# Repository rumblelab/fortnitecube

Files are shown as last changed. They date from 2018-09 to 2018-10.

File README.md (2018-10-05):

# How to build your own Fortnite purple cube - Kevin

In this repo you will find: 
1. [Ardunio code](https://github.com/rumblelab/fortnitecube/tree/master/FortnitePurpleCube)
2. [.STL files for 3D printing the cube](https://github.com/rumblelab/fortnitecube/tree/master/3dKevin)
3. [BOM - Bill of Materials and links to each item](https://github.com/rumblelab/fortnitecube/blob/master/FortniteCube_BOM.pdf)
4. [Version 2: BOM - Bill of Materials and links to each item](https://github.com/rumblelab/fortnitecube/blob/master/V2_FortniteCube_BOM.pdf)
5. Wiring diagram 
6. .OGG sound file 

## Contributing to the code:
Please feel free to contribute! We appreciate any and all suggestions to help make the code for this project more efficient. Submit your ideas and we will review.

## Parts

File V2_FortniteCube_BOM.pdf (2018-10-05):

## VERSION TWO:

## Fortnite Purple Cube (Kevin) - Bill of Materials

## Created by Moultrie Ball

### RumbleLab (http://www.rumblelab.com)

If you’d like more detailed instructions, comment on our YouTube video here. (https://youtu.be/xSYryboQGLk)

Item | Price | Link | Notes
Piezo Element | $1.50 | SparkFun (https://www.sparkfun.com/products/10293)
Micro Servo | $5.95 | Adafruit (https://www.adafruit.com/product/169)
Audio Amplifier | $3.95 | Adafruit (https://www.adafruit.com/product/2130)
FX Mini Sound Board | $14.95 | Adafruit (https://www.adafruit.com/product/2342)
Trinket - Mini Microcontroller | $6.95 | Adafruit (https://www.adafruit.com/product/1501) | *Need 2 of these
Lithium Ion Battery | $7.95 | Adafruit (https://www.adafruit.com/product/1578)
(2) 40mm Round External Magnet Electronic Speakers | $7.37 | Amazon (https://www.amazon.com/gp/product/B00XXG5GX4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) | We’d love your help in supporting our channel. Affiliate link here: Amazon (https://amzn.to/2Rz2iX0)
On-Off Power Button | $1.95 | Adafruit (https://www.adafruit.com/product/1683)
Lilon/LiPoly Backpack Add-On for Pro Trinket | $4.95 | Adafruit (https://www.adafruit.com/product/2124)
NeoPixel Digital RGB LED Strip - White 60 LED - 1 meter | $24.95 | Adafruit (https://www.adafruit.com/product/1138?length=1)
Maker Paste | $6.95 | Adafruit (https://www.adafruit.com/product/3217) | Only get this if you don’t want to use a soldering iron
30 AWG Flexible Silicone Wire (Non-affiliate link) | $9.74 | Amazon (https://www.amazon.com/gp/product/B01KQ2JNLI/ref=oh_aui_detailpage_o02_s00?ie=UTF8&psc=1) | We’d love your help in supporting our channel. Affiliate link here: Amazon (https://amzn.to/2NrdWUm)
Hatchbox 3D Printer Filament - Glow in the Dark (Non-affiliate link) | $26.99 | Amazon (https://www.amazon.com/gp/product/B00M0CS73S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) | We’d love your help in supporting our channel. Affiliate link here: Amazon (https://amzn.to/2oLxHZ7)

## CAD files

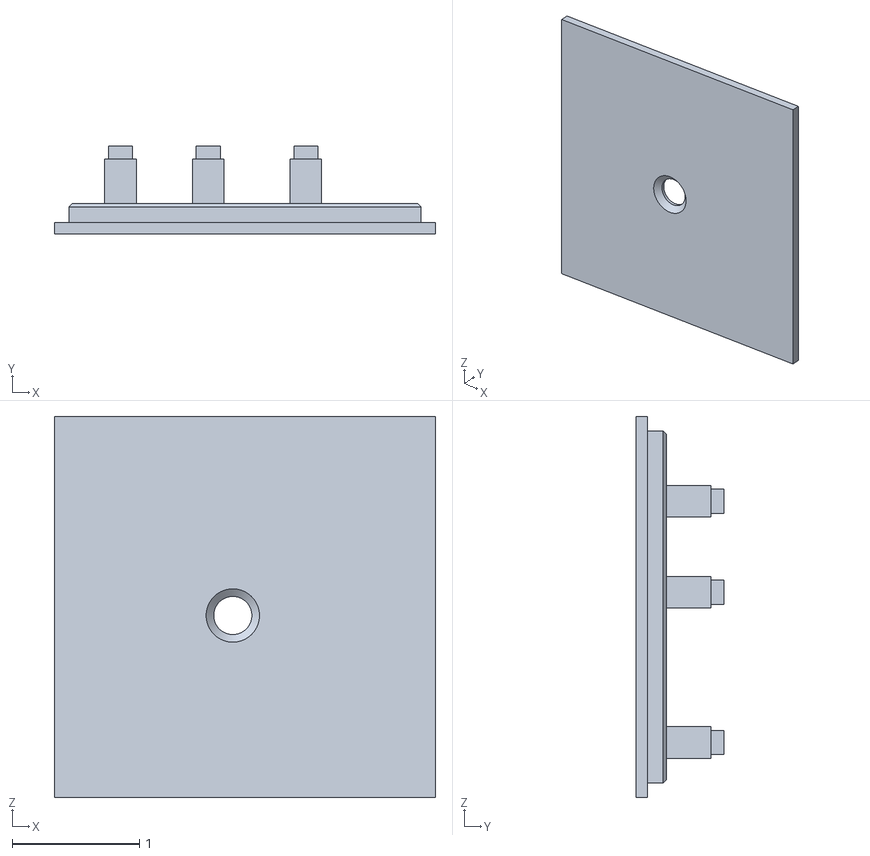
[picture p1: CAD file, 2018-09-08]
3dKevin/KevinBase.stl
3.00 x 0.69 x 3.00

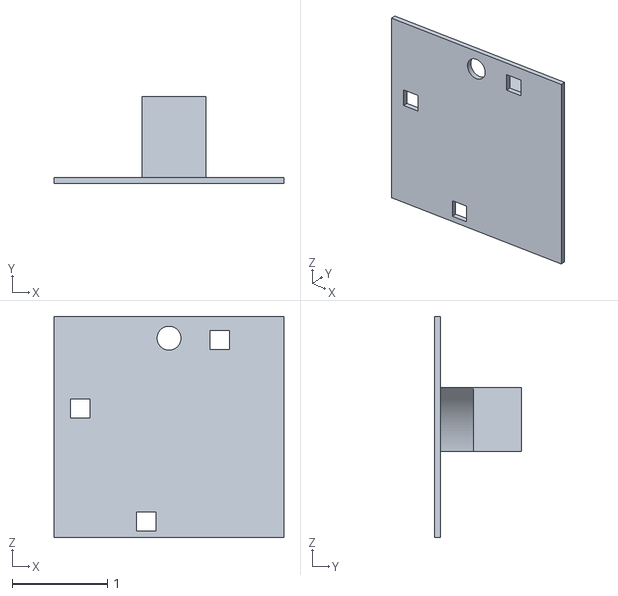
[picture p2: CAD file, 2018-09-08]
3dKevin/TopHat.stl
2.41 x 0.91 x 2.32

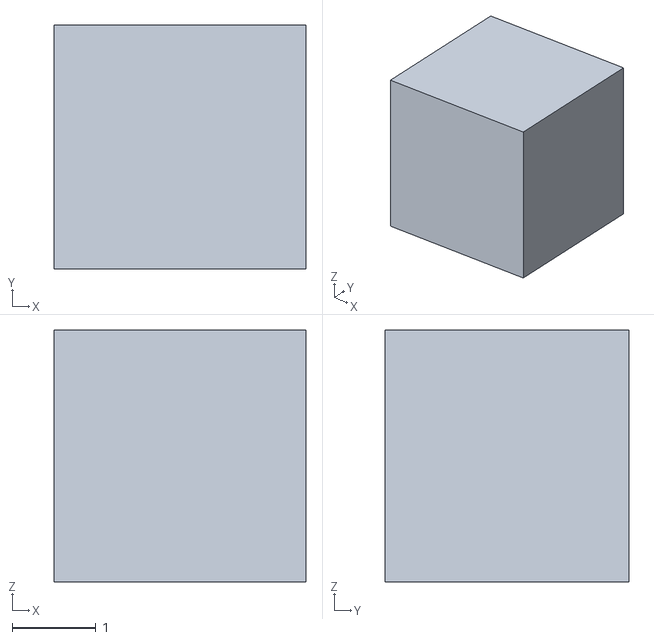
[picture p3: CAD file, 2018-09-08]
3dKevin/KevinBody.stl
3.00 x 2.90 x 3.00

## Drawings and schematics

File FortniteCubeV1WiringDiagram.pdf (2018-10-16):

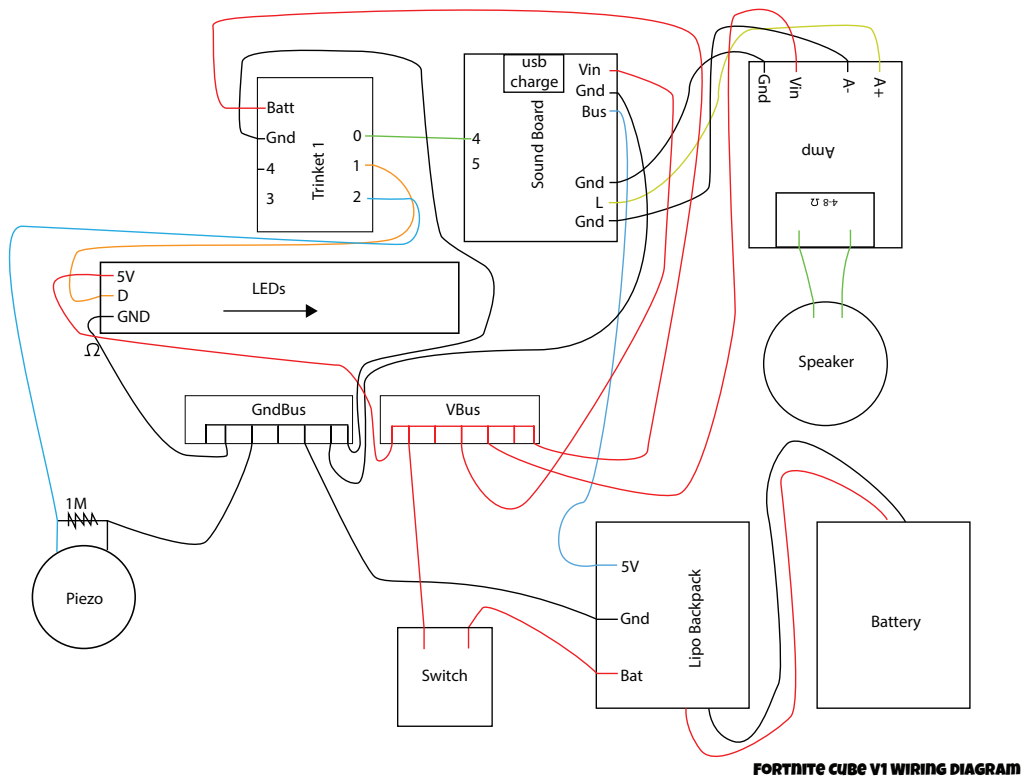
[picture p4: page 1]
Sound Board; Speaker; Battery; Lipo Backpack; Vin Gnd; Gnd; Bus; Trinket 1; Batt; Switch; Bat; Vin; GndBus; VBus; LEDs; GND; Piezo; usb charge

Fortnite Cube V1 Wiring Diagram

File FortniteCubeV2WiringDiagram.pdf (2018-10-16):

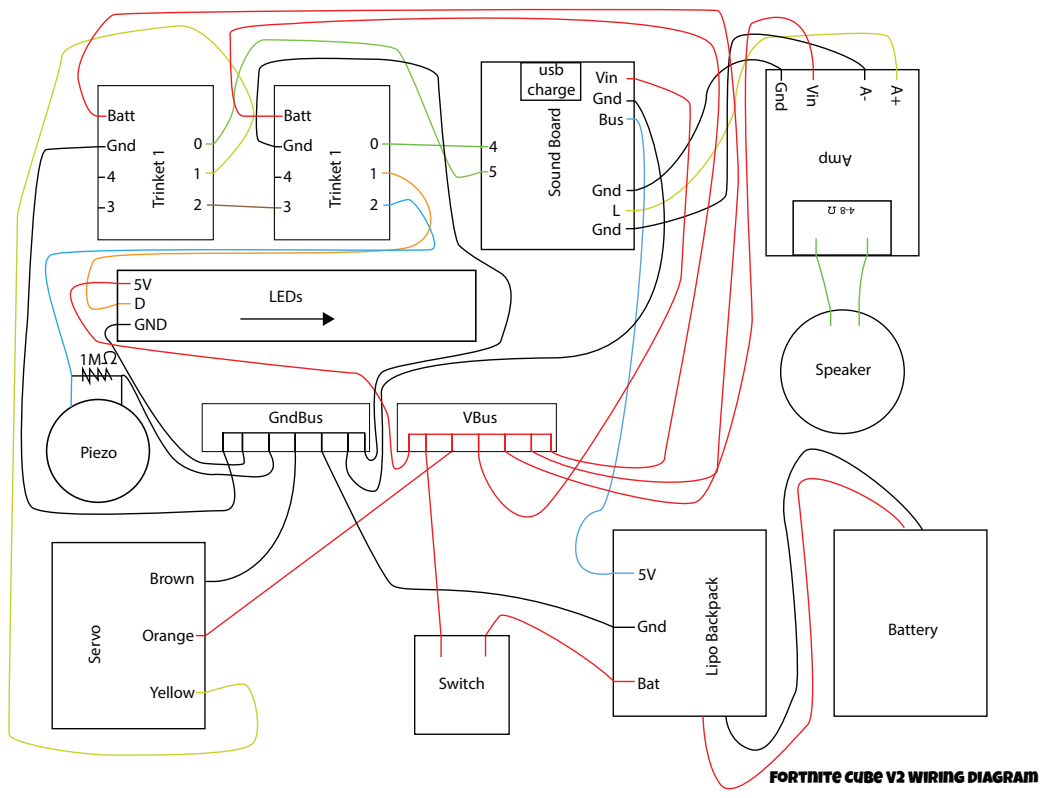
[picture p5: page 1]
Trinket 1; Sound Board; Speaker; Servo; Battery; Lipo Backpack; Vin Gnd; Gnd; Bus; Batt; Brown; Orange; Yellow; Switch; Bat; Vin; GndBus; VBus; LEDs; GND; Piezo; usb charge

Fortnite Cube V2 Wiring Diagram

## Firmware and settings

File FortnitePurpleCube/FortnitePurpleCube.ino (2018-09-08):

#include <Adafruit_NeoPixel.h>
#ifdef __AVR__
  #include <avr/power.h>
#endif
//increase this value to make Kevin less sensitive, decrease it to make him more sensitive
int accelThreshold = 2;

//Give Pin's on the trinket a purpose
int ledPIN = 1;
int sfxPin = 0;

//Tell the program, how many LED's we will use
int NUMPIXELS = 5;

//initialize variables for us to do some math with later
int prevAccelVal = 0;
int currentAccelVal = 0;
int accelDiff = 0;
int lastHitTime = 0;//variable to debounce Kevin...why do people call it debounce
int currentHitTime = 0;
int delayBetweenHits = 3000;
int timeBetweenHits = 0;

bool justFired = true;//boolean to make sure that kevin doesnt fire back to back
bool kevinIsHit = false;//boolean to control when to complete the lightning strike routine

//Define a Neopixel object "strip" that we will use in our program
Adafruit_NeoPixel strip = Adafruit_NeoPixel(NUMPIXELS, ledPIN, NEO_GRB + NEO_KHZ800);

void setup() {
  // This is for Trinket 5V 16MHz, you can remove these three lines if you are not using a Trinket
  #if defined (__AVR_ATtiny85__)
    if (F_CPU == 16000000) clock_prescale_set(clock_div_1);
  #endif

  //initialize pins
  pinMode(sfxPin , OUTPUT);
  digitalWrite(sfxPin , HIGH);
  
  // Wake up Neopixels, it's time to get to work...
  strip.begin(); 
  strip.show();
  
  //start Kevin out in a laid back mood  
  kevinIsCalm();
}

void loop() {
  
  checkForStrike();
  
  if(kevinIsHit){
  kevinIsMad();
  }
      
  else{
    kevinIsCalm(); 
  }
}

  //function to check if Kevin was hit
  void checkForStrike(){
    prevAccelVal = currentAccelVal;
    currentAccelVal = analogRead(1);
    currentAccelVal = analogRead(1);
    accelDiff = abs(currentAccelVal - prevAccelVal);
    if(accelDiff>accelThreshold){
      currentHitTime = millis();
      timeBetweenHits = currentHitTime - lastHitTime;
      if(timeBetweenHits>delayBetweenHits){//we need a delay between hits to keep funny things from happening
          kevinIsHit = true;
          lastHitTime = millis();
      }

  }

  else{
    kevinIsHit = false;
  }
}
  //take Kevin back to his happy place
void kevinIsCalm(){
  for (int i = 0 ; i<NUMPIXELS ; i++){
  strip.setPixelColor(i, 10, 10, 10);
  }
  strip.show();
}

void playAngryKevinSound(){
  digitalWrite(sfxPin , LOW);//sending the sfx pin to ground causes sound to play
}

void resetSfxPin(){
  digitalWrite(sfxPin , HIGH);
}

void kevinIsMad(){
  playAngryKevinSound();
  //gradually get a little brighter
  for (int j = 10; j < 50 ; j++){
    for (int i = 0 ; i<NUMPIXELS ; i++){
    strip.setPixelColor(i, j, j, j);
    }
    strip.show();
    delay(24);
}
  resetSfxPin();

  //fire lightning
    for (int j = 20; j < 250 ; j++){
    for (int i = 0 ; i<NUMPIXELS ; i++){
    strip.setPixelColor(i, j, j, j);
    }
    strip.show();
}

//gradually dim colors back to Kevin's happy color
for (int j = 250; j > 10 ; j--){
    for (int i = 0 ; i<NUMPIXELS ; i++){
    strip.setPixelColor(i, j, j, j);
    }
    strip.show();
    delay(1);
}

//Kevin got out his anger, now reset him
kevinIsHit = false;
}

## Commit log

2018-09-08 adds 3d print files
    [KevinBase.stl, KevinBody.stl, TopHat.stl]
2018-09-09 adds BOM PDF
2018-09-09 Deletes old BOM pdf
2018-09-09 adds updated Fortnite Cube BOM
2018-09-09 updates link to BOM
2018-10-05 adds version two BOM
2018-10-05 adds version 2 link to BOM
2018-10-16 Uploaded a basic wiring diagram
    This is for V2 of the Fortnite Cube
2018-10-16 Cube V1 Wiring Diagram
2018-10-16 Cube Angry Sound
    Wav File that plays when Pin 4 is grounded on the sound board
